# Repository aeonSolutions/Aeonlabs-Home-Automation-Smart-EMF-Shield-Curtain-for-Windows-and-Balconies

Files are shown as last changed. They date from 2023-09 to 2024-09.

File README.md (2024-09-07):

<p align="center">
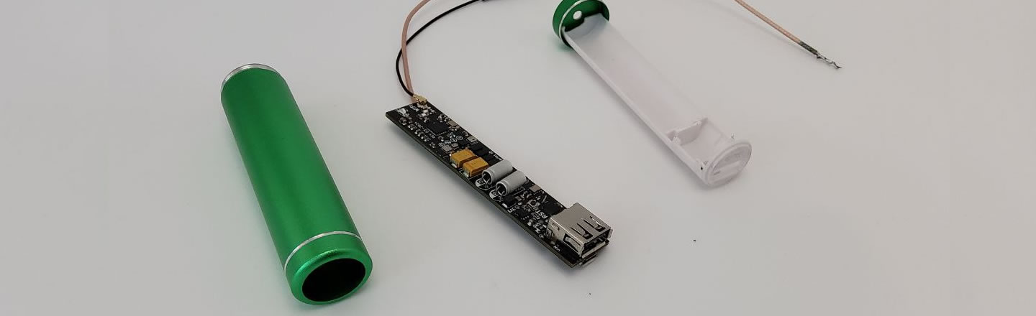
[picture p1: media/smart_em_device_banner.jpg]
   
</p>


 
 

<a href="https://trackgit.com">
trackgit-views
</a>




[](https://www.buymeacoffee.com/migueltomas)

**Navigation** | [AeonLabs Main Index](https://github.com/aeonSolutions/aeonSolutions/blob/main/aeonSolutions-Main-Index.md)  >>  [Open Hardware Electronics](https://github.com/aeonSolutions/PCB-Prototyping-Catalogue)   >>   [Home-Automation](https://github.com/aeonSolutions/PCB-Prototyping-Catalogue/tree/main/Home-Automation)  >>  [Safety & Health](https://github.com/aeonSolutions/AeonLabs-Safety-Health)     >>  Smart EMF Shield Curtain for Windows and Balconies

<p align="right">
 <a href="https://github-com.translate.goog/aeonSolutions/Aeonlabs-Home-Automation-Smart-EMF-Shield-Curtain-for-Windows-and-Balconies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">Change language</a> <br>
Last update 07-09-2024 <br> <br>
partially sponsored by <br> 
    <a href="https://www.seeedstudio.com/fusion.html">
       
    </a>
</p>

⚠️ **Start by reading the documentation first**. [Click here to open it](https://github.com/aeonSolutions/AeonLabs-Safety-Health/wiki) 

# Smart EMF Shield Curtain for Windows and Balconies

<p align="left"> 
  
<b>Status:</b>
 Hardware electronics are Fully tested and working. The first 🥇 release of the firmware code is now available. <br>
&nbsp; Looking for someone available to collaborate on the firmware coding. If you like this project and want faster development, prototyping, and testing consider a donation or sponsoring. thank you 🙏.
 </p>

<p align="center">  
   <a href="https://www.hackster.io/mtpsilva/an-open-smart-device-for-emf-emp-monitoring-in-a-window-5b020f">
      
   </a>
</p>

## The problem
nowadays many are sensitive to electromagnetic frequency radiation mainly due to excessive exposure above natural and healthy limits. There are many solutions to mitigate exposure to this kind of radiation however none have the ability to collect EMF energy values directly from a window or access door to a balcony.

## The idea
This smart device is intended to be installed and fixed into a copper electromagnetic (EM) shield on any EM indoor window or balcony door. It has the main ability to collect EM sensor data from the curtain itself and send it to a public data repository, for instance, a #dataverse (see www.dataverse.org)

<p align="center">
  <a href="https://www.customtintsolutions.com/window-film-benefits/rf-blocking/" target="_blank">
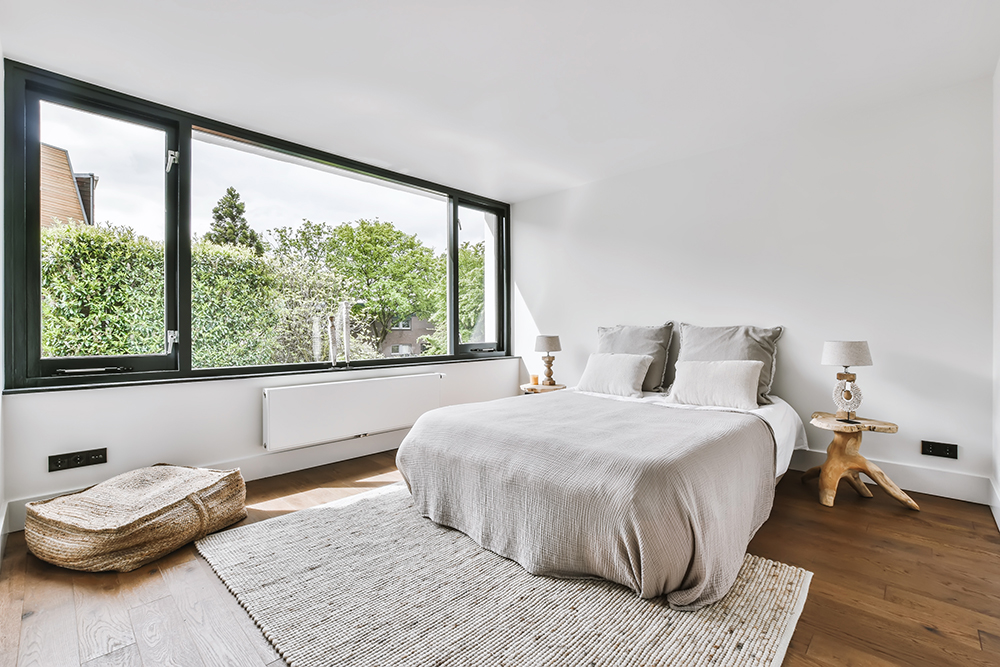
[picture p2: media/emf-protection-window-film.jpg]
      </a> <br>
   <sup> Figure 1- Example of a window in a room where this Smart Device can be installed</sup>
</p>

## Total Cost of this Project
The total cost of this project to date is listed below:
- Work hours dedicated to this project: >300 w.h <br>
  This includes research and study about Bio EM RF, building this repository, and other useless miscellaneous online tasks. <br>
  hardware electronics assembly and testing, several times.
- Electronic components  >200 eur
- Aluminium Enclosure Case and other materials ~20 eur ( [buy one on AliExpress ](https://s.click.aliexpress.com/e/_DkqC3wL) )

<p align="center">
    <a href="https://github.com/aeonSolutions/PCB-Prototyping-Catalogue/blob/main/become_a_sponsor/aeonlabs-github-sponsorship-agreement.docx">
        
    </a>
    <a href="https://github.com/sponsors/aeonSolutions">
        
    </a>
</p>

See [here](https://github.com/aeonSolutions/AeonLabs-Safety-Health) who sponsored, to this date, the Safety & Health project. 

<br>

## Important Information
The smart safety & health solution is for the kind of wireless aggression that behaves like ripples in a pond. For instance Wireless electromagnetic radios, including those found on smartphones, tablets, wifi routers at home, and many more.

**This smart device is not able to detect wireless aggressions targeted to a person's body and individual. For instance, using some kind of beam-forming device or technologies**. For example, Laser and laser-like kind of devices and kind of technologies. 

**When installing this smart solution, take action and be conscious that the aggression/aggressor may change to other types and kinds of "wireless devices" this smart device is unable to detect**.  

**Always use this smart device connected to a public data repository with LIVE data streams. At the same time, notify the authorities immediately and provide the web address link where the public data repository can be found**. Data repositories based on Harvard's www.dataverse.org are currently the most suited (not ideal) for the smart solution provided. 

**Be advised**

Known open data repositories partially compatible with these smart devices:
- www.dataverse.org [partial compatible] (open firmware provided here uses a dataverse repository API)
- www.figshare.com [partial compatible]
- www.datadryad.org [not compatible; no API]

<br>

<p align="center">
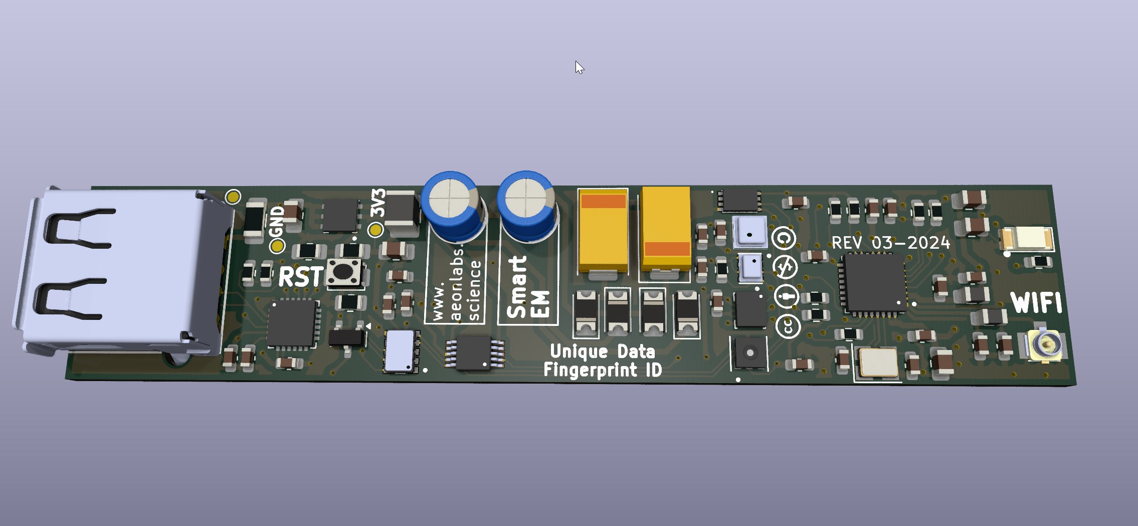
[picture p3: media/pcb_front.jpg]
     <br>
 <sup> Figure 2 - 3D rendering in KiCad of the hardware electronics </sup>
</p>

<p align="center">
<strong> <a href="https://aeonsolutions.github.io/sponsor/em_radiation/">Interactive view of the PCB Layout</a> </strong> &nbsp;
  <strong> <a href="https://aeonsolutions.github.io/sponsor/em_radiation//circuit_schematic.html">Interactive view of the circuit schematic</a> </strong> <br>
 <sup>Click to view the latest revision</sup>
</p>

This device is designed to burn out every time an electromagnetic pulse, spark, or other EMF has a too-high energy. This way the victim can use the burnt device as evidence when presenting a complaint to the authorities.

stay safe.

<p align="center">
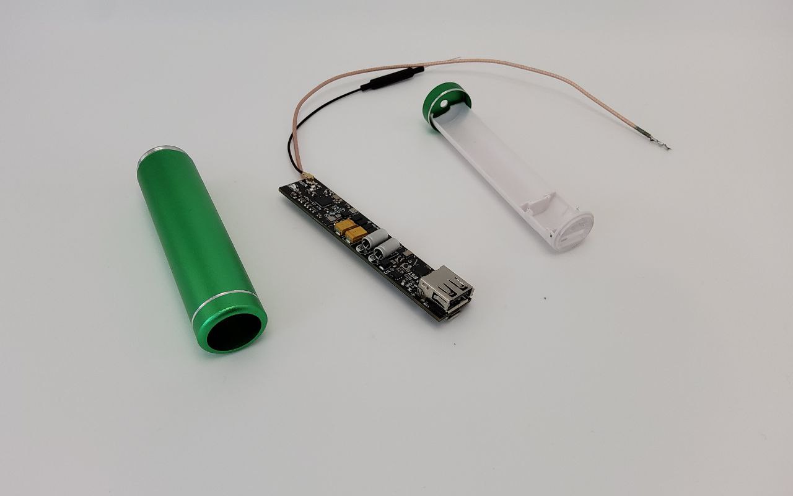
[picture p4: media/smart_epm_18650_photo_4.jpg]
    <br>
 <sup> Figure 3 - Smart EM Device Already Assemble and ready to be installed on the Aluminium Enclosure</sup>
</p>

## Compatibility

<p align="center">
 <a href"https://www.apple.com/shop/accessories/all/homekit">

 </a>
<a href="https://home.google.com"> 
 
 </a>
<a href="https://www.home-assistant.io">  
 
 </a>
<a href="https://csa-iot.org/all-solutions/matter/">  
 
 </a>
<a href="https://csa-iot.org/all-solutions/matter/">  
 
 </a>
</p>

###  Status
  Hardware electronics are Fully tested and working. The first 🥇 release of the firmware code is now available.
  
  <p align="center">


</p>

[January 1, 2024] - The firmware 1.0.0 for Over the Air Updates is now released to the public. Goto the [releases section](https://github.com/aeonSolutions/Aeonlabs-Home-Automation-Smart-EMF-Shield-Curtain-for-Windows-and-Balconies/releases/tag/openFirmware) to learn more.  

<br>

## OEM Firmware code
The OEM version of the firmware code can be found in the folder **OEM firmware code**.  It has by default OTA updates, meaning the smart concrete curing device automatically updates it self when newer updated versions are made available here.  

This code uses my own ESP32 C++ class libraries to expedite the development of the code of ESP32 microcontrollers. The repository is located in the [open source software section](https://github.com/aeonSolutions/aeonlabs-ESP32-C-Base-Firmware-Libraries#readme).

#### Send the collected sensor data to this repository
On this repository, there's a special folder, named [datasets](https://github.com/aeonSolutions/AeonLabs-Safety-Health/tree/main/Measurements/datasets), where anyone is able to upload dataset files directly from their open smart devices. This folder is intended to facilitate sharing of "electromagnetic" measurements among anyone with interest and capable of studying and analyzing it in search of EM anomalies to improve detection of the open hardware electronics made available here. **Anyone is invited to participate, cost-free**. 

&nbsp;&nbsp; To assist you with the firmware programming, there's a C++ test code compatible with all Arduino devices that anyone can use to speed up the programming of the open smart device. Here's the link: <br>
https://github.com/aeonSolutions/Aeonlabs-Arduino_Hardware_Test_Code/tree/main/github_api_test_upload <br>
Any questions on how to do it, send me a message on the Discord Server:

<div align="center">



</div>

<br>

## What one additionally needs
- [USB to UART/USB TTL firmware burner for 5V and 3.3V MCUs ](https://github.com/aeonSolutions/PCB-Prototyping-Catalogue/blob/main/DIY-Maker/README.md)
- [Radiation Shield Curtain](https://s.click.aliexpress.com/e/_DC76f4j) or any other conducting material or conductive glass window
  <p align="center"> 
 <a href="https://s.click.aliexpress.com/e/_DC76f4j" target="_blank">
     
  </a>
</p>

- [4.2V Lipo Battery](https://s.click.aliexpress.com/e/_Dl3iRpl)
  
<br />
<br />

**Get a Notification on every PCB update**

| [](https://www.tindie.com/stores/aeonlabs/) | You can fill in your [email here (Google form)](https://docs.google.com/forms/d/e/1FAIpQLScErMgQYRdA-umvCjvTPPrCO7Lg1QYowTxb7vfa8cTfrcPEAA/viewform?usp=pp_url) and I'll send a reminder when a new PCB prototype is made available here or a new revision for an existing PCB. Stay tuned! |
|---|---|

<br>

<br />
<br />

## Author

You can get in touch with me on my LinkedIn Profile:

#### Miguel Tomas



<a href="https://stackexchange.com/users/18907312/miguel-silva">profile for Miguel Silva on Stack Exchange, a network of free, community-driven Q&A sites</a>



You can also follow my GitHub Profile to stay updated about my latest projects: 

<br>

**Hire me** <br>
See [here](https://github.com/aeonSolutions/PCB-Prototyping-Catalogue/wiki/How-to-Hire-AeonLabs) how to hire AeonLabs.

<br>

### Be supportive of my dedication and work towards technology education and buy me a cup of coffee
The PCB design Files I provide here for anyone to use are free. If you like this Smart Device or use it, please consider buying me a cup of coffee, a slice of pizza, or a book to help me study, eat, and think new PCB design files.

<p align="center">
    <a href="https://www.buymeacoffee.com/migueltomas">
        
    </a>
</p>

### Make a donation on PayPal
Make a donation on PayPal and get a TAX refund*.

<p align="center">
    <a href="http://paypal.me/mtpsilva">
        
    </a>
</p>

### Support all these open hardware projects and become a GitHub sponsor  
Did you like any of my PCB KiCad Designs? Help and Support my open work to all by becoming a GitHub sponsor.

<p align="center">
    <a href="https://github.com/aeonSolutions/PCB-Prototyping-Catalogue/blob/main/become_a_sponsor/aeonlabs-github-sponsorship-agreement.docx">
        
    </a>
    <a href="https://github.com/sponsors/aeonSolutions">
        
    </a>
</p>

### License

Before proceeding to download any of AeonLabs open source code for software solutions and/or open hardware electronics for smart devices and data acquisition make sure you are choosing the right license for your project. See [AeonLabs Solutions for Open Hardware & Open Source Code](https://github.com/aeonSolutions/PCB-Prototyping-Catalogue/wiki/AeonLabs-Solutions-for-Open-Hardware-&-Source-Development) for more information. For commercial business solutions contact AeonLabs for more information ℹ️ using the contacts above. Thank you 🙏.

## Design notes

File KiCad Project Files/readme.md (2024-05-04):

[PCB-Prototyping-Catalogue](https://github.com/aeonSolutions/PCB-Prototyping-Catalogue)  >>   [Home-Automation](https://github.com/aeonSolutions/PCB-Prototyping-Catalogue/tree/main/Home-Automation)  >>  [Home Automation Safety & Health](https://github.com/aeonSolutions/PCB-Prototyping-Catalogue/blob/main/Home%20Automation%20Safety%20%26%20Health/readme.md)   >>  Smart EMF Shield Curtain for Windows and Balconies

<p align="right">
 <a href="https://github-com.translate.goog/aeonSolutions/Aeonlabs-Home-Automation-Smart-EMF-Shield-Curtain-for-Windows-and-Balconies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">Change language</a> <br>
Last update 04-05-2024 <br> <br>
partially sponsored by <br> 
    <a href="https://www.seeedstudio.com/fusion.html">
       
    </a>
</p>

<br>

This folder contains the KiCad Project files, for the hardware electronics of the Smart EMF Shield Curtain for Windows and Balconies.  Each KiCad project is available with a [creative commons share alike non-commercial license](https://creativecommons.org/licenses/by-nc-sa/4.0/deed.en). 

<p align="center">
<strong> <a href="https://aeonsolutions.github.io/sponsor/em_radiation/">Interactive view of the PCB Layout</a> </strong> &nbsp;
  <strong> <a href="https://aeonsolutions.github.io/sponsor/em_radiation//circuit_schematic.html">Interactive view of the circuit schematic</a> </strong> <br>
 <sup>Click to view the latest revision</sup>
</p>

However, they're not fully complete. If you like it and are looking to use it on your projects, you can download the complete Kicad project files with a one-time donation, [click here](https://github.com/sponsors/aeonSolutions) to learn how,  and don't forget to include it in a message the name of the module/hardware electronics you need. <br> Thank you 🙏.

### Support all these open hardware projects and become a GitHub sponsor  
Did you like any of my PCB KiCad Designs? Help and Support my open work to all by becoming a GitHub sponsor.

<p align="center">
    <a href="https://github.com/aeonSolutions/PCB-Prototyping-Catalogue/blob/main/become_a_sponsor/aeonlabs-github-sponsorship-agreement.docx">
        
    </a>
    <a href="https://github.com/sponsors/aeonSolutions">
        
    </a>
</p>

#

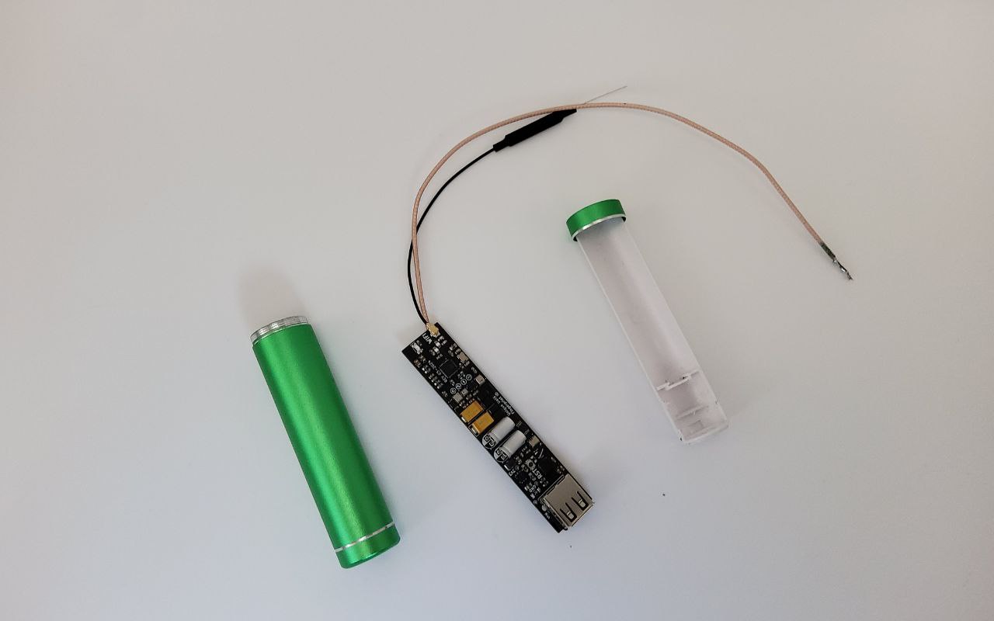
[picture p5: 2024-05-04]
media/smart_epm_18650_photo_3.jpg

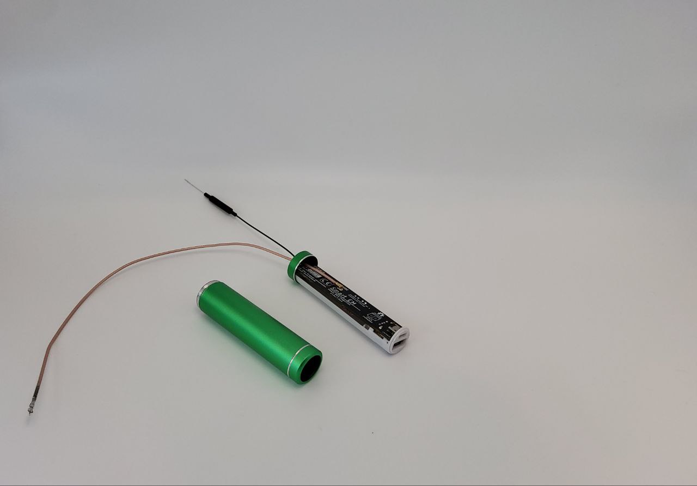
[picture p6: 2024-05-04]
media/smart_epm_18650_photo_2.jpg

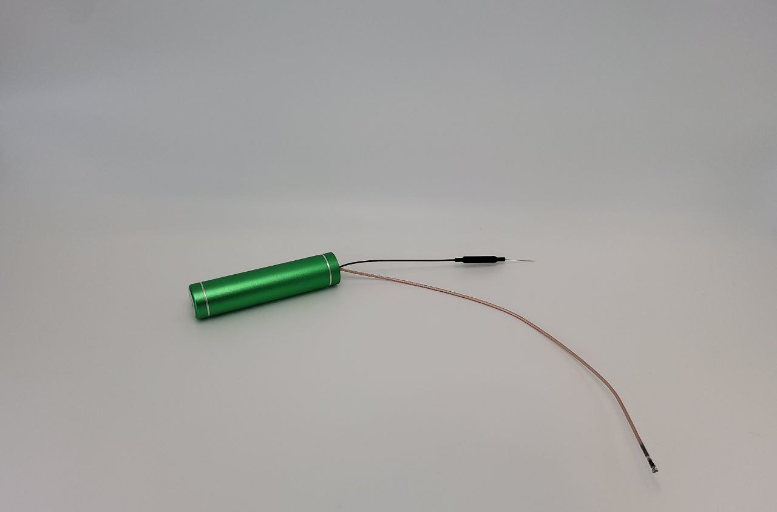
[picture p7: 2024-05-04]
media/smart_epm_18650_photo_1.jpg

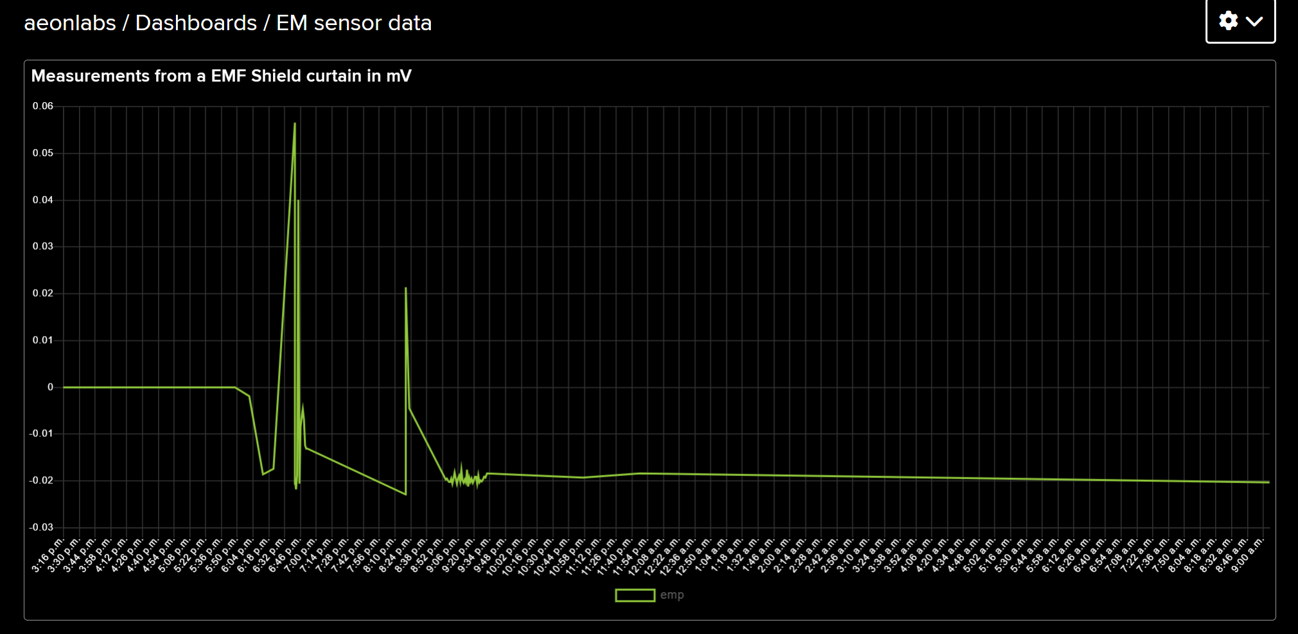
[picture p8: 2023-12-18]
media/emf_data_plot.png

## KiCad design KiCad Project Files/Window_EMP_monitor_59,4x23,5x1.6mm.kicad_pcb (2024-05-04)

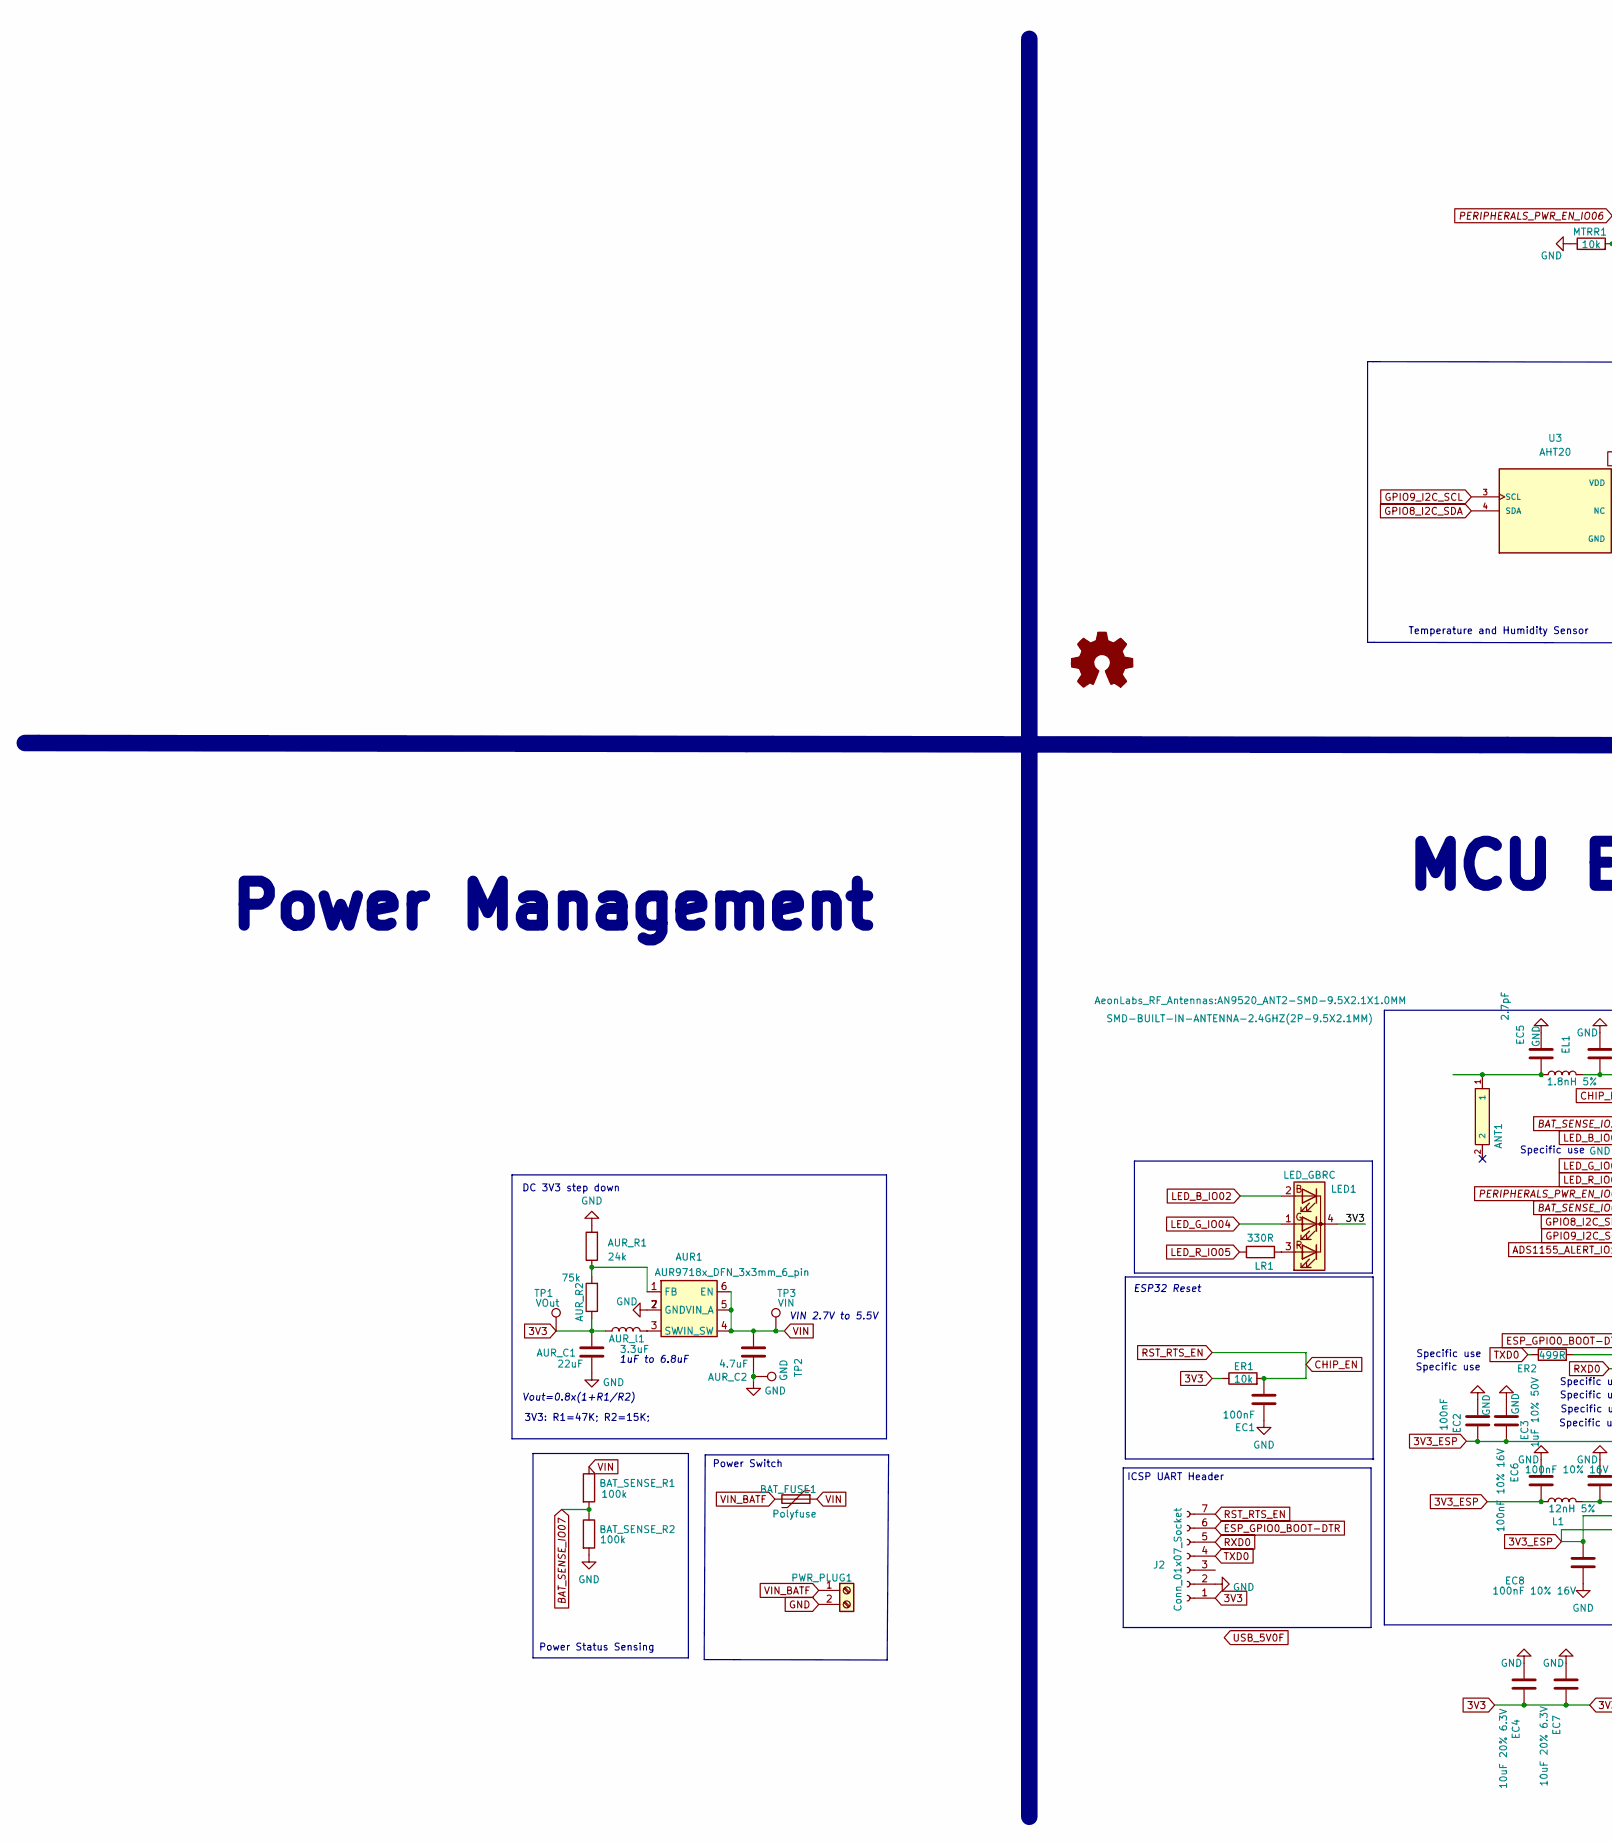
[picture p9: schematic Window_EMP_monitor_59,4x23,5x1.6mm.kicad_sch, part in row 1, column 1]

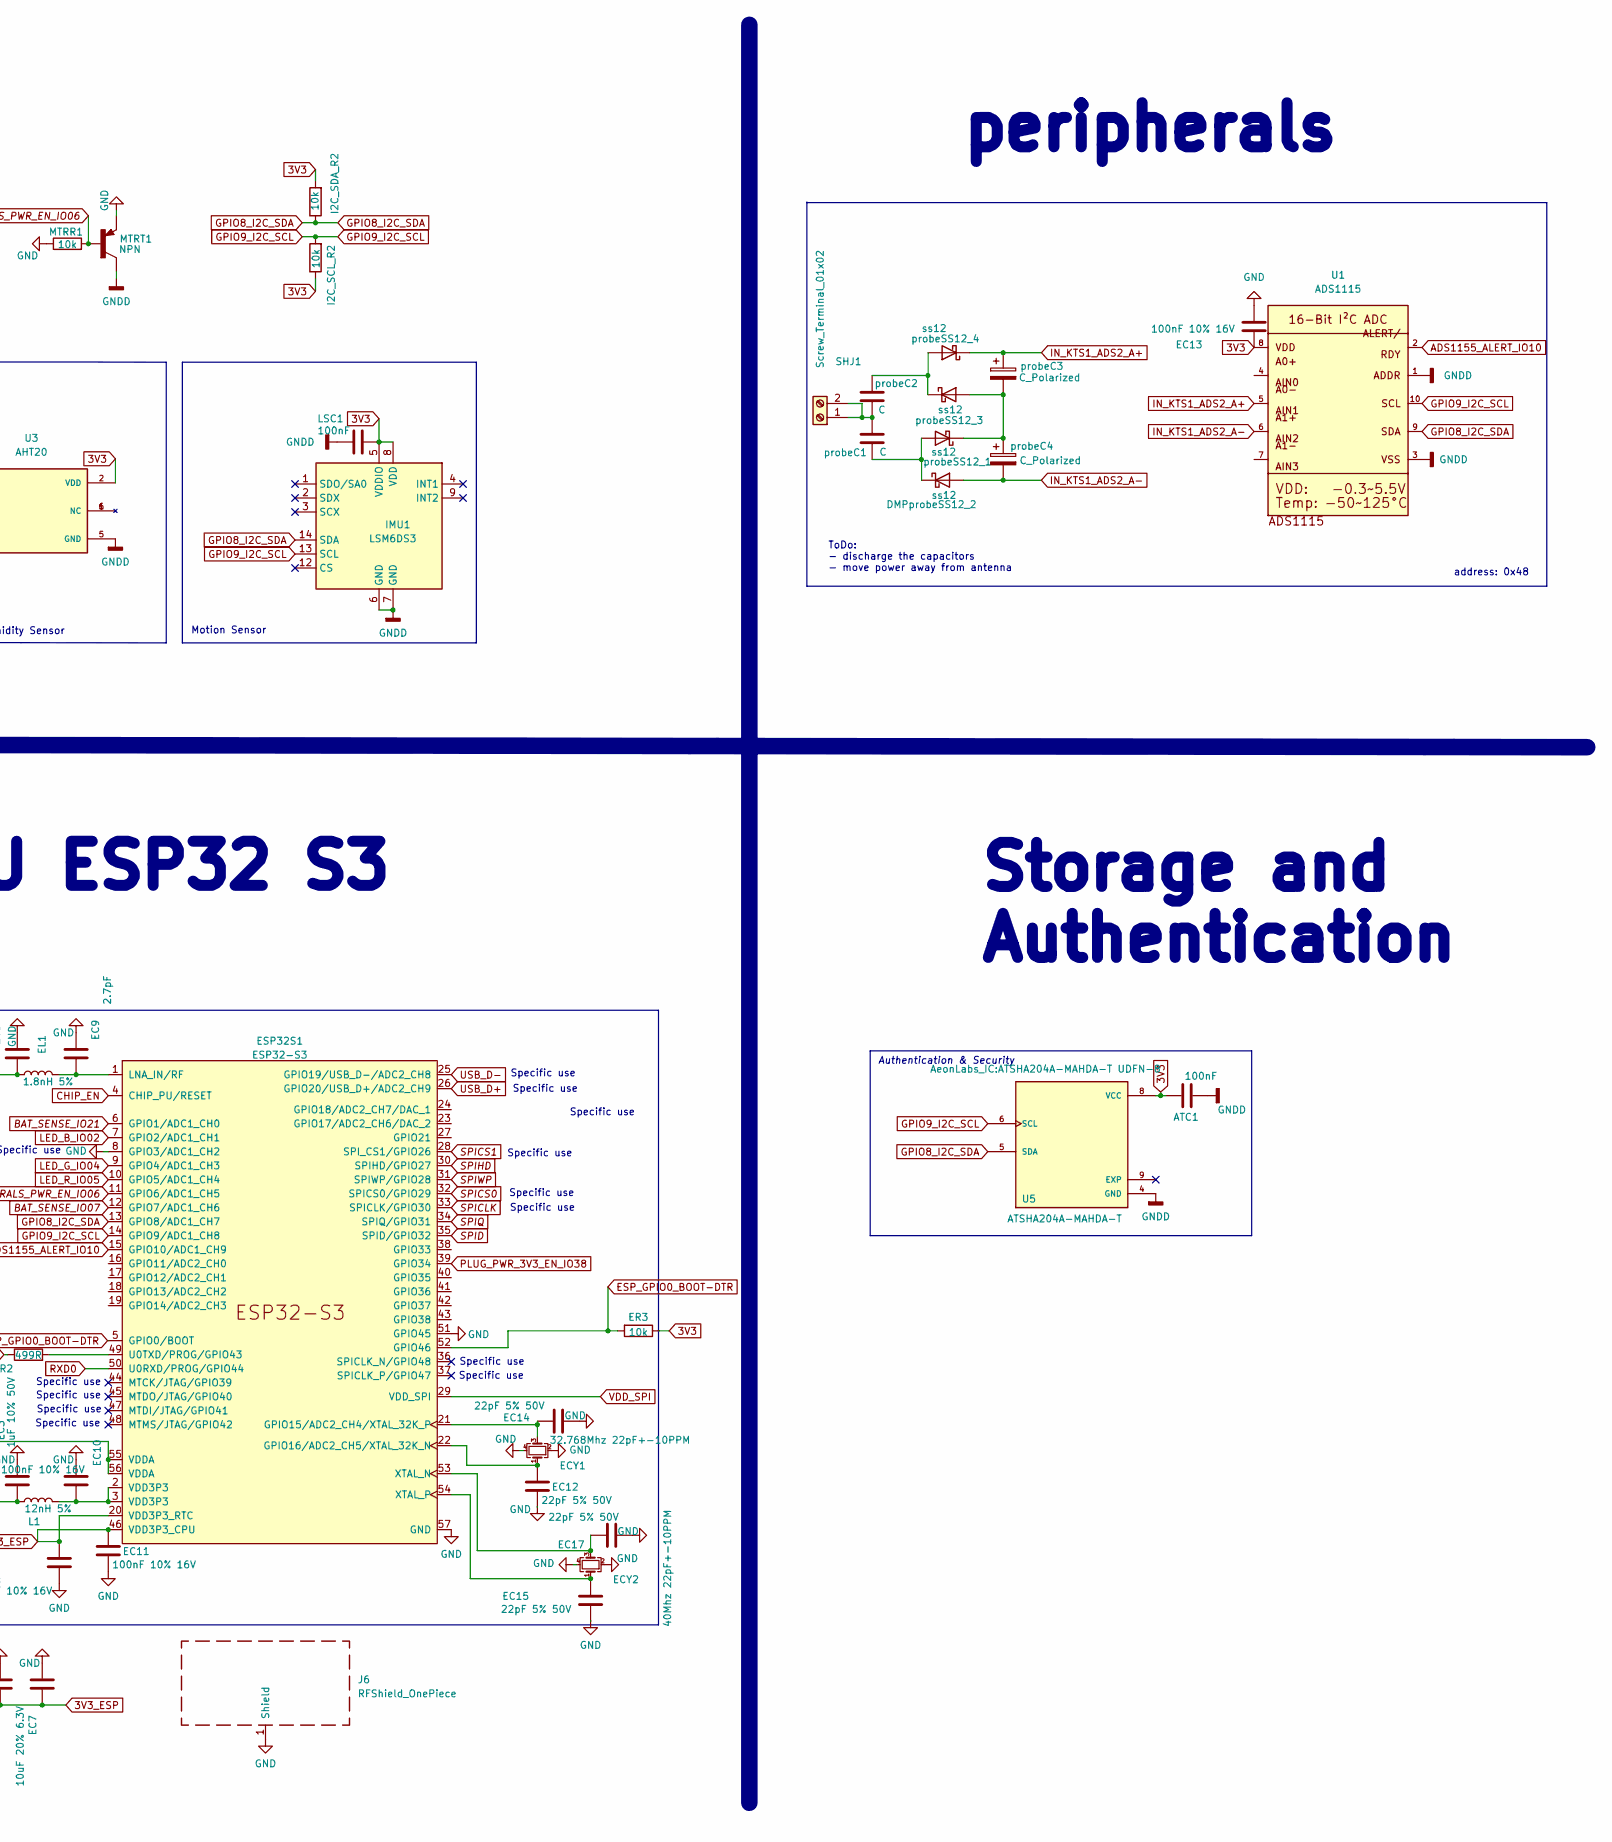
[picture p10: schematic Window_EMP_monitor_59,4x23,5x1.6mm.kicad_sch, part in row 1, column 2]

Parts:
ANT1: SMD-BUILT-IN-ANTENNA-2.4GHZ(2P-9.5X2.1MM); AN9520_ANT2-SMD-9.5X2.1X1.0MM
ATC1: 100nF; C_0603_1608Metric
AUR1: AUR9718x_DFN_3x3mm_6_pin; AUR9718 ST1S09 SON95P300X300X100-7N
AUR_C1: 22uF; C_0805_2012Metric_Pad1.18x1.45mm_HandSolder
AUR_C2: 4.7uF; C_0805_2012Metric_Pad1.18x1.45mm_HandSolder
AUR_R1: 24k; R_0805_2012Metric_Pad1.20x1.40mm_HandSolder
AUR_R2: 75k; R_0805_2012Metric_Pad1.20x1.40mm_HandSolder
AUR_l1: 3.3uF; L_1210_3225Metric
BAT_FUSE1: Polyfuse; Fuse_1206_3216Metric_Pad1.42x1.75mm_HandSolder
BAT_SENSE_R1, BAT_SENSE_R2: 100k; R_0603_1608Metric
DMPprobeSS12_2: ss12; D_1206_3216Metric
EC1, EC2: 100nF; C_0603_1608Metric
EC3: 1uF 10% 50V; C_0805_2012Metric
EC4, EC7: 10uF 20% 6.3V; C_0805_2012Metric
EC5, EC9: 2.7pF; C_0603_1608Metric
EC6, EC8, EC10, EC11, EC13: 100nF 10% 16V; C_0603_1608Metric
EC12, EC14, EC15, EC17: 22pF 5% 50V; C_0603_1608Metric
ECY1: 32.768Mhz 22pF+-10PPM; Crystal_SMD_3225-4Pin_3.2x2.5mm
ECY2: 40Mhz 22pF+-10PPM; Crystal_SMD_3225-4Pin_3.2x2.5mm
EL1: 1.8nH 5%; L_0805_2012Metric
ER1, ER3: 10k; R_0603_1608Metric
ER2: 499R; R_0603_1608Metric
ESP32S1: ESP32-S3; QFN-56-1EP_7x7mm_P0.4mm_EP5.6x5.6mm
I2C_SCL_R2, I2C_SDA_R2: 10k; R_0603_1608Metric
IMU1: LSM6DS3; LSM6DS3 PQFN50P300X250X86-14N
J2: Conn_01x07_Socket; SOIC_clipProgSmall
J6: RFShield_OnePiece; ESP32-S3 GND Shield
L1: 12nH 5%; L_0805_2012Metric
LED1: LED_GBRC; LED_1206_3210_RGB_Metric
LR1: 330R; R_0603_1608Metric
LSC1: 100nF; C_0603_1608Metric
MTRR1: 10k; R_0805_2012Metric
MTRT1: NPN; SOT-23; PARTREV C2001
PWR_PLUG1: Screw_Terminal_01x02; JST_EH_S2B-EH_1x02_P2.50mm_Horizontal
SHJ1: Screw_Terminal_01x02; JST_SH_SM02B-SRSS-TB_1x02-1MP_P1.00mm_Horizontal
TP1: VOut; TestPoint_Pad_D1.0mm
TP2: GND; TestPoint_Pad_D1.0mm
TP3: VIN; TestPoint_Pad_D1.0mm
U1: ADS1115; ASD1155
U3: AHT20; AHT20 PSON100P300X300X110-6N; PARTREV V1.0
U5: ATSHA204A-MAHDA-T; ATSHA204A-MAHDA-T UDFN-8; PART_REV A
probeC1, probeC2: C; CP_EIA-7343-31_Kemet-D
probeC3, probeC4: C_Polarized; CP_Radial_D5.0mm_P2.50mm
probeSS12_1, probeSS12_3, probeSS12_4: ss12; D_1206_3216Metric

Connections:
3V3: ATC1.2, AUR_C1.1, AUR_R2.1, AUR_l1.1, EC2.2, EC3.2, EC4.1, EC6.1, EC7.1, EC8.1, EC11.1, EC13.2, ER1.1, ER3.1, ESP32S1.20 (VDD3P3_RTC), ESP32S1.46 (VDD3P3_CPU), ESP32S1.55 (VDDA), ESP32S1.56 (VDDA), I2C_SCL_R2.1, I2C_SDA_R2.2, IMU1.5 (VDDIO), IMU1.8 (VDD), J2.1, L1.1, LED1.4 (K), LSC1.1, TP1.1, U1.8, U3.2 (VDD), U5.8 (VCC)
ADS1155_ALERT_IO10: ESP32S1.15 (GPIO10/ADC1_CH9), U1.2
BAT_SENSE_IO07: BAT_SENSE_R1.2, BAT_SENSE_R2.1, ESP32S1.12 (GPIO7/ADC1_CH6)
BAT_SENSE_IO21: ESP32S1.6 (GPIO1/ADC1_CH0)
CHIP_EN: EC1.2, ER1.2, ESP32S1.4 (CHIP_PU/RESET), J2.7
ESP_GPIO0_BOOT-DTR: ER3.2, ESP32S1.5 (GPIO0/BOOT), ESP32S1.52 (GPIO46), J2.6
GND: AUR1.2 (GND), AUR1.7 (GND), AUR_C1.2, AUR_C2.2, AUR_R1.2, BAT_SENSE_R2.2, EC1.1, EC2.1, EC3.1, EC4.2, EC5.2, EC6.2, EC7.2, EC8.2, EC9.2, EC10.2, EC11.2, EC12.2, EC13.1, EC14.2, EC15.2, EC17.2, ECY1.2, ECY1.4, ECY2.2, ECY2.4, ESP32S1.8 (GPIO3/ADC1_CH2), ESP32S1.51 (GPIO45), ESP32S1.57 (GND), J2.2, MTRR1.1, MTRT1.2, PWR_PLUG1.2, TP2.1
GNDD: ATC1.1, IMU1.6 (GND), IMU1.7 (GND), LSC1.2, MTRT1.3, U1.1, U1.3, U3.5 (GND), U5.4 (GND)
GPIO8_I2C_SDA: ESP32S1.13 (GPIO8/ADC1_CH7), I2C_SDA_R2.1, IMU1.14 (SDA), U1.9, U3.4 (SDA), U5.5 (SDA)
GPIO9_I2C_SCL: ESP32S1.14 (GPIO9/ADC1_CH8), I2C_SCL_R2.2, IMU1.13 (SCL), U1.10, U3.3 (SCL), U5.6 (SCL)
IN_KTS1_ADS2_A+: U1.5, probeC3.1, probeSS12_4.1 (K)
IN_KTS1_ADS2_A-: DMPprobeSS12_2.2 (A), U1.6, probeC4.2
LED_B_IO02: ESP32S1.7 (GPIO2/ADC1_CH1), LED1.2 (BA)
LED_G_IO04: ESP32S1.9 (GPIO4/ADC1_CH3), LED1.1 (GA)
LED_R_IO05: ESP32S1.10 (GPIO5/ADC1_CH4), LR1.1
unnamed: ANT1.1, EC5.1, EL1.1
unnamed: AUR1.1 (FB), AUR_R1.1, AUR_R2.2
unnamed: AUR1.3 (SW), AUR_l1.2
unnamed: DMPprobeSS12_2.1 (K), probeC1.2, probeSS12_1.2 (A)
unnamed: EC10.1, ESP32S1.2 (VDD3P3), ESP32S1.3 (VDD3P3), L1.2
unnamed: EC14.1, ECY1.3, ESP32S1.21 (GPIO15/ADC2_CH4/XTAL_32K_P)
unnamed: EC12.1, ECY1.1, ESP32S1.22 (GPIO16/ADC2_CH5/XTAL_32K_N)
unnamed: EC9.1, EL1.2, ESP32S1.1 (LNA_IN/RF)
unnamed: ER2.2, ESP32S1.49 (U0TXD/PROG/GPIO43)
unnamed: EC17.1, ECY2.3, ESP32S1.53 (XTAL_N)
unnamed: EC15.1, ECY2.1, ESP32S1.54 (XTAL_P)
unnamed: LED1.3 (RA), LR1.2
unnamed: SHJ1.1, SHJ1.2, probeC1.1, probeC2.2
unnamed: probeC3.2, probeC4.1, probeSS12_1.1 (K), probeSS12_3.2 (A)
unnamed: probeC2.1, probeSS12_3.1 (K), probeSS12_4.2 (A)
PERIPHERALS_PWR_EN_IO06: ESP32S1.11 (GPIO6/ADC1_CH5), MTRR1.2, MTRT1.1
PLUG_PWR_3V3_EN_IO38: ESP32S1.39 (GPIO34)
RXD0: ESP32S1.50 (U0RXD/PROG/GPIO44), J2.5
SPICLK: ESP32S1.33 (SPICLK/GPIO30)
SPICS0: ESP32S1.32 (SPICS0/GPIO29)
SPICS1: ESP32S1.28 (SPI_CS1/GPIO26)
SPID: ESP32S1.35 (SPID/GPIO32)
SPIHD: ESP32S1.30 (SPIHD/GPIO27)
SPIQ: ESP32S1.34 (SPIQ/GPIO31)
SPIWP: ESP32S1.31 (SPIWP/GPIO28)
TXD0: ER2.1, J2.4
USB_D+: ESP32S1.26 (GPIO20/USB_D+/ADC2_CH9)
USB_D-: ESP32S1.25 (GPIO19/USB_D-/ADC2_CH8)
VDD_SPI: ESP32S1.29 (VDD_SPI)
VIN: AUR1.4 (VIN_SW), AUR1.5 (VIN_A), AUR1.6 (EN), AUR_C2.1, BAT_FUSE1.1, BAT_SENSE_R1.1, TP3.1
VIN_BATF: BAT_FUSE1.2, PWR_PLUG1.1

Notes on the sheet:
Specific use
peripherals
DC 3V3 step down
Power Switch
address: 0x48
Temperature and Humidity Sensor
Power Status Sensing
ToDo: - discharge the capacitors - move power away from antenna
Vout=0.8x(1+R1/R2)
Motion Sensor
ESP32 Reset
1uF to 6.8uF
Storage and Authentication
Power Management
ICSP UART Header
MCU ESP32 S3
Authentication & Security
VIN 2.7V to 5.5V
3V3: R1=47K; R2=15K;

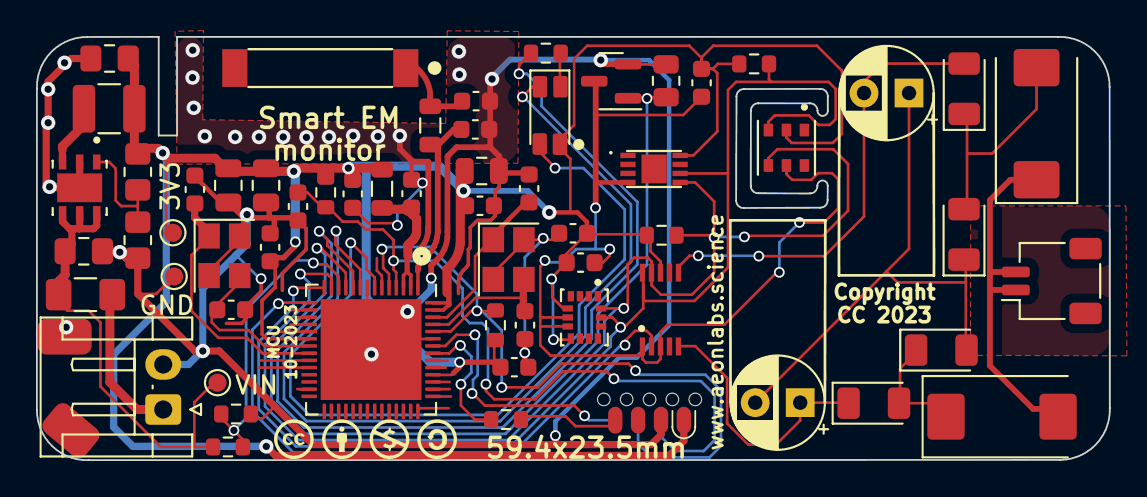
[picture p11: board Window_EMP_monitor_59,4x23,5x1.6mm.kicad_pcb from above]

Board: 2 copper layers, 59.6 x 23.5 mm, 60 parts (0 on the bottom side), 34 nets.

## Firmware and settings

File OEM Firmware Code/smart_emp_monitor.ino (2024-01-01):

/*
  Copyright (c) 2023 Miguel Tomas, http://www.aeonlabs.science

  License Attribution-NonCommercial-ShareAlike 4.0 International (CC BY-NC-SA 4.0)
  You are free to:
   Share — copy and redistribute the material in any medium or format
   Adapt — remix, transform, and build upon the material

  The licensor cannot revoke these freedoms as long as you follow the license terms. Under the following terms:
  Attribution — You must give appropriate credit, provide a link to the license, and indicate if changes were made.
  You may do so in any reasonable manner, but not in any way that suggests the licensor endorses you or your use.

  NonCommercial — You may not use the material for commercial purposes.

  ShareAlike — If you remix, transform, or build upon the material, you must distribute your contributions under
  the same license as the original.

  No additional restrictions — You may not apply legal terms or technological measures that legally restrict others
  from doing anything the license permits.

  Notices:
  You do not have to comply with the license for elements of the material in the public domain or where your use
  is permitted by an applicable exception or limitation.
  No warranties are given. The license may not give you all of the permissions necessary for your intended use.
  For example, other rights such as publicity, privacy, or moral rights may limit how you use the material.


  Before proceeding to download any of AeonLabs software solutions for open-source development
  and/or PCB hardware electronics development make sure you are choosing the right license for your project. See
  https://github.com/aeonSolutions/PCB-Prototyping-Catalogue/wiki/AeonLabs-Solutions-for-Open-Hardware-&-Source-Development
  for Open Hardware & Source Development for more information.

*/

#define uS_TO_S_FACTOR 1000000

/************************* Adafruit.io Setup *********************************/
//required message queue telemetry transport protocol to subscribe and publish feeds
#include "Adafruit_MQTT.h"
#include "Adafruit_MQTT_Client.h"

// the adafruit server to connect
#define AIO_SERVER    "io.adafruit.com"

// the port to connect
#define AIO_SERVERPORT 1883

// get this key from your own Adafruit Account
#define AIO_USERNAME "XXXXXXXX"
#define AIO_KEY "XXXXXXXXXXXXXXXXXXX"
#include <WiFi.h>
WiFiClient wclient;

Adafruit_MQTT_Client mqtt(&wclient, AIO_SERVER, AIO_SERVERPORT, AIO_USERNAME, AIO_KEY);

//Feeds Settings

//temperature value that will be read through BMP180 sensor
Adafruit_MQTT_Publish temp = Adafruit_MQTT_Publish(&mqtt, AIO_USERNAME "/feeds/temp");

//pressure value that will be read through BMP180 sensor
Adafruit_MQTT_Publish humidity = Adafruit_MQTT_Publish(&mqtt, AIO_USERNAME "/feeds/humidity");

//altitude value that will be read through BMP180 sensor
Adafruit_MQTT_Publish emp = Adafruit_MQTT_Publish(&mqtt, AIO_USERNAME "/feeds/emp");


//----------------------------------------------------------------------------------------
// Components Testing  **************************************
bool SCAN_I2C_BUS = false;
bool TEST_FINGERPRINT_ID_IC = false;

//----------------------------------------------------------------------------------
#include <math.h>
#include <cmath>
#include "SPI.h"
#include <semphr.h>

#include "esp32-hal-psram.h"
// #include "rom/cache.h"
extern "C"
{
#include <esp_himem.h>
#include <esp_spiram.h>
}

#include <Wire.h>
// custom includes **********************************
#include "nvs_flash.h"  //preferences lib

// External sensor moeasurements
#include "telegram_emp.h"
TELEGRAM_EMP_CLASS* telegram = new TELEGRAM_EMP_CLASS();

// custom functions
#include "m_file_functions.h"

// Interface class ******************************
#include "interface_class.h"
INTERFACE_CLASS* interface = new INTERFACE_CLASS();
#define DEVICE_NAME "EMP Monitor"

// GBRL commands  ***************************
#include "gbrl.h"
GBRL gbrl = GBRL();

// Onboard sensors  *******************************
#include "onboard_sensors.h"
ONBOARD_SENSORS* onBoardSensors = new ONBOARD_SENSORS();

//
#include <Adafruit_ADS1X15.h>
Adafruit_ADS1115 ads;  /* Use this for the 16-bit version */
// Pin connected to the ALERT/RDY signal for new sample notification.
constexpr int READY_PIN = 10;


// unique figerprint data ID
#include "m_atsha204.h"

// serial comm
#include <HardwareSerial.h>
HardwareSerial UARTserial(0);

#include "mserial.h"
mSerial* mserial = new mSerial(true, nullptr);

// File class
#include <esp_partition.h>
#include "FS.h"
#include <LittleFS.h>
#include "m_file_class.h"

FILE_CLASS* drive = new FILE_CLASS(mserial);

// WIFI Class
#include <ESP32Ping.h>
#include "m_wifi.h"
#include "esp_wifi.h"
M_WIFI_CLASS* mWifi = new M_WIFI_CLASS();

// Certificates
#include "cert/github_cert.h"

/********************************************************************/
#include <BLEDevice.h>
#include <BLEServer.h>
#include <BLEUtils.h>
#include <BLE2902.h>

// See the following for generating UUIDs:
// https://www.uuidgenerator.net/

#define SERVICE_UUID           "6E400001-B5A3-F393-E0A9-E50E24DCCA9E" // UART service UUID
#define CHARACTERISTIC_UUID_RX "6E400002-B5A3-F393-E0A9-E50E24DCCA9E"
#define CHARACTERISTIC_UUID_TX "6E400003-B5A3-F393-E0A9-E50E24DCCA9E"

BLECharacteristic *pCharacteristicTX, *pCharacteristicRX;
BLEServer *pServer;
BLEService *pService;


bool BLE_advertise_Started = false;

bool newValueToSend = false;
String $BLE_CMD = "";
bool newBLESerialCommandArrived = false;
SemaphoreHandle_t MemLockSemaphoreBLE_RX = xSemaphoreCreateMutex();

float txValue = 0;
String valueReceived = "";


class MyServerCallbacks: public BLEServerCallbacks {
    void onConnect(BLEServer* pServer) {
      mWifi->setBLEconnectivityStatus (true);
      mserial->printStr("BLE connection init ", mserial->DEBUG_BOTH_USB_UART);

      interface->onBoardLED->led[0] = interface->onBoardLED->LED_BLUE;
      interface->onBoardLED->statusLED(100, 1);

      String dataStr = "Connected to the Smart Concrete Maturity device (" + String(interface->firmware_version) + ")" + String(char(10)) + String(char(13)) + "Type $? or $help to see a list of available commands" + String(char(10));
      dataStr += String(interface->rtc.getDateTime(true)) + String(char(10)) + String(char(10));

      if (mWifi->getNumberWIFIconfigured() == 0 ) {
        dataStr += "no WiFi Networks Configured" + String(char(10)) + String(char(10));
      }
      //interface->sendBLEstring(dataStr, mserial->DEBUG_TO_BLE);
    }

    void onDisconnect(BLEServer* pServer) {
      mWifi->setBLEconnectivityStatus (false);

      interface->onBoardLED->led[0] = interface->onBoardLED->LED_BLUE;
      interface->onBoardLED->statusLED(100, 0.5);
      interface->onBoardLED->led[0] = interface->onBoardLED->LED_RED;
      interface->onBoardLED->statusLED(100, 0.5);
      interface->onBoardLED->led[0] = interface->onBoardLED->LED_BLUE;
      interface->onBoardLED->statusLED(100, 0.5);

      pServer->getAdvertising()->start();
    }
};

class pCharacteristicTX_Callbacks: public BLECharacteristicCallbacks {
    void onWrite(BLECharacteristic *pCharacteristic) {
      String txValue = String(pCharacteristic->getValue().c_str());
      txValue.trim();
      mserial->printStrln("Transmitted TX Value: " + String(txValue.c_str()) , mserial->DEBUG_BOTH_USB_UART);

      if (txValue.length() == 0) {
        mserial->printStr("Transmitted TX Value: empty ", mserial->DEBUG_BOTH_USB_UART);
      }
    }

    void onRead(BLECharacteristic *pCharacteristic) {
      mserial->printStr("TX onRead...", mserial->DEBUG_BOTH_USB_UART);
      //pCharacteristic->setValue("OK");
    }
};

class pCharacteristicRX_Callbacks: public BLECharacteristicCallbacks {
    void onWrite(BLECharacteristic *pCharacteristic) {
      delay(10);

      String rxValue = String(pCharacteristic->getValue().c_str());
      rxValue.trim();
      mserial->printStrln("Received RX Value: " + String(rxValue.c_str()), mserial->DEBUG_BOTH_USB_UART );

      if (rxValue.length() == 0) {
        mserial->printStr("Received RX Value: empty " , mserial->DEBUG_BOTH_USB_UART);
      }

      $BLE_CMD = rxValue;
      mWifi->setBLEconnectivityStatus(true);

      xSemaphoreTake(MemLockSemaphoreBLE_RX, portMAX_DELAY);
      newBLESerialCommandArrived = true; // this needs to be the last line
      xSemaphoreGive(MemLockSemaphoreBLE_RX);

      delay(50);
    }

    void onRead(BLECharacteristic *pCharacteristic) {
      mserial->printStr("RX onRead..." , mserial->DEBUG_BOTH_USB_UART);
      //pCharacteristic->setValue("OK");
    }

};

// ********************************************************
// *************************  == SETUP == *****************
// ********************************************************
//variaveis que indicam o núcleo
static uint8_t taskCoreZero = 0;
static uint8_t taskCoreOne  = 1;

long int prevMeasurementMillis;


void setup() {
  ESP_ERROR_CHECK(nvs_flash_erase());
  nvs_flash_init();

  interface->settings_defaults();
  // Firmware Build Version / revision ______________________________
  interface->firmware_version = "1.0.0";

  // Serial Communication Init ______________________________
  interface->UARTserial = nullptr; // &UARTserial;
  mserial->DEBUG_TO = mserial->DEBUG_TO_UART;
  mserial->DEBUG_EN = true;
  mserial->DEBUG_TYPE = mserial->DEBUG_TYPE_VERBOSE; // DEBUG_TYPE_INFO;

  mserial->start(115200);

  // ......................................................................................................
  // .......................... START OF IO & PIN CONFIGURATION..............................................
  // ......................................................................................................

  // I2C IOs  __________________________
  interface->I2C_SDA_IO_PIN = 8;
  interface->I2C_SCL_IO_PIN = 9;
  int I2C_PWR_PIN=6;
  
  pinMode(I2C_PWR_PIN, OUTPUT);
  digitalWrite(I2C_PWR_PIN, HIGH);
  
  // WIRE.begin: SDA, SCL, FREQ
  bool result = Wire.begin( interface->I2C_SDA_IO_PIN , interface->I2C_SCL_IO_PIN ); //, 100000 );
  
  // Power Saving ____________________________________
  interface->LIGHT_SLEEP_EN = true;


  // ________________ Onboard LED  _____________
  interface->onBoardLED = new ONBOARD_LED_CLASS();
  interface->onBoardLED->LED_RED = 5;
  interface->onBoardLED->LED_BLUE = 2;
  interface->onBoardLED->LED_GREEN = 4;

  interface->onBoardLED->LED_RED_CH = 4;
  interface->onBoardLED->LED_BLUE_CH = 1;
  interface->onBoardLED->LED_GREEN_CH = 3;

  // ___________ MCU freq ____________________
  interface-> SAMPLING_FREQUENCY = 80;
  interface-> WIFI_FREQUENCY = 80; // min WIFI MCU Freq is 80-240
  interface->MIN_MCU_FREQUENCY = 80;
  interface-> SERIAL_DEFAULT_SPEED = 115200;

// _____________________ TELEGRAM _____________________________
  telegram->OWNER_CHAT_ID = "xxxxxxxxxxxx";
  // Initialize Telegram BOT
  telegram->BOTtoken = "xxxxxxxxxxxxxxxxxxxxxxxxxxxxxxxxxxx";  // your Bot Token (Get from Botfather)

  // ......................................................................................................
  // .......................... END OF IO & PIN CONFIGURATION..............................................
  // ......................................................................................................

  interface->onBoardLED->init();

  interface->onBoardLED->led[0] = interface->onBoardLED->LED_RED;
  interface->onBoardLED->statusLED(100, 0);

  //init storage drive ___________________________
  drive->partition_info();
  if (drive->init(LittleFS, "storage", 2, mserial,   interface->onBoardLED ) == false)
    while (1);

  //init interface ___________________________
  interface->init(mserial, true); // debug EN ON

  if ( !interface->loadSettings() ) {
    interface->onBoardLED->led[0] = interface->onBoardLED->LED_RED;
    interface->onBoardLED->led[0] = interface->onBoardLED->LED_GREEN;
    interface->onBoardLED->statusLED(100, 2);
  }

  // init onboard sensors ___________________________
  onBoardSensors->init(interface, mserial);

  if (SCAN_I2C_BUS) {
    onBoardSensors->I2Cscanner();
  }
  onBoardSensors->initOnboardSensors();

  mserial->printStrln("Getting differential reading from AIN0 (P) and AIN1 (N)");
  mserial->printStrln("ADC Range: +/- 6.144V (1 bit = 3mV/ADS1015, 0.1875mV/ADS1115)");

  // The ADC input range (or gain) can be changed via the following
  // functions, but be careful never to exceed VDD +0.3V max, or to
  // exceed the upper and lower limits if you adjust the input range!
  // Setting these values incorrectly may destroy your ADC!
  //                                                                ADS1015  ADS1115
  //                                                                -------  -------
  ads.setGain(GAIN_TWOTHIRDS);  // 2/3x gain +/- 6.144V  1 bit = 3mV      0.1875mV (default)
  // ads.setGain(GAIN_ONE);        // 1x gain   +/- 4.096V  1 bit = 2mV      0.125mV
  // ads.setGain(GAIN_TWO);        // 2x gain   +/- 2.048V  1 bit = 1mV      0.0625mV
  // ads.setGain(GAIN_FOUR);       // 4x gain   +/- 1.024V  1 bit = 0.5mV    0.03125mV
  // ads.setGain(GAIN_EIGHT);      // 8x gain   +/- 0.512V  1 bit = 0.25mV   0.015625mV
  // ads.setGain(GAIN_SIXTEEN);    // 16x gain  +/- 0.256V  1 bit = 0.125mV  0.0078125mV

  if (!ads.begin()) {
    mserial->printStrln("Failed to initialize ADS.");
  }
  pinMode(READY_PIN, INPUT);
  
 
  // Data Authenticity IC
  if (TEST_FINGERPRINT_ID_IC) {
    mserial->printStrln("Testing the Unique FingerPrind ID for Sensor Data Measurements");

    mserial->printStr("This Smart Device  Serial Number is : ");
    mserial->printStrln(CryptoICserialNumber(interface));

    mserial->printStrln("Testing Random Genenator: " + CryptoGetRandom(interface));
    mserial->printStrln("");

    mserial->printStrln("Testing Sensor Data Validation hashing");
    mserial->printStrln( macChallengeDataAuthenticity(interface, "TEST IC"));
    mserial->printStrln("");
  }

  mserial->printStrln("\nMicrocontroller specifications:");
  interface->CURRENT_CLOCK_FREQUENCY = getCpuFrequencyMhz();
  mserial->printStr("Internal Clock Freq = ");
  mserial->printStr(String(interface->CURRENT_CLOCK_FREQUENCY));
  mserial->printStrln(" MHz");

  interface->Freq = getXtalFrequencyMhz();
  mserial->printStr("XTAL Freq = ");
  mserial->printStr(String(interface->Freq));
  mserial->printStrln(" MHz");

  interface->Freq = getApbFrequency();
  mserial->printStr("APB Freq = ");
  mserial->printStr(String(interface->Freq / 1000000));
  mserial->printStrln(" MHz");

  interface->setMCUclockFrequency( interface->WIFI_FREQUENCY);
  mserial->printStrln("setting Boot MCU Freq to " + String(getCpuFrequencyMhz()) +"MHz");
  mserial->printStrln("");

  // init BLE
  BLE_init();

    // init BLE
  BLE_init();

  //init wifi
  mWifi->init(interface, drive, interface->onBoardLED);
  mWifi->setTxPower = WIFI_POWER_8_5dBm;
  mWifi->OTA_FIRMWARE_SERVER_URL = "https://github.com/aeonSolutions/openScience-Smart-DAQ-to-Upload-Live-Experimental-Data-to-a-Data-Repository/releases/download/openFirmware/firmware.bin";
  
  mWifi->add_wifi_network("XXXXXXXXXXXXXXX","XXXXXXXXXXXXXXXX");
  mWifi->ALWAYS_ON_WIFI = false;

  mWifi->WIFIscanNetworks(true);

  // check for firmwate update
  mWifi->startFirmwareUpdate();
  
  mserial->printStrln( "\nRequesting Geo Location FingerPrint  =====================================" );
  mWifi->get_ip_geo_location_data("", true);
  
  ESP32Time rtc(0);
  rtc.setTime( mWifi->requestGeoLocationDateTime );

  mserial->printStrln("Internet IP       : " + mWifi->InternetIPaddress );
  mserial->printStrln("Geo Location Time : " + String( rtc.getDateTime(true) ) );
  if ( mWifi->geoLocationInfoJson.isNull() == false ){
    float lat =0.0f;
    float lon = 0.0f;

    if( mWifi->geoLocationInfoJson.containsKey("lat")){
      lat = mWifi->geoLocationInfoJson["lat"];
      mserial->printStr( "Latitude : " + String(lat,4) );
    }else{
      mserial->printStr( "Latitude : - -" );
    }

    if( mWifi->geoLocationInfoJson.containsKey("lon")){
      lon = mWifi->geoLocationInfoJson["lon"];
      mserial->printStr( "  Longitude: " + String(lon,4) );
    }else{
      mserial->printStr( "  Longitude: - -" );
    }
    
    if( mWifi->geoLocationInfoJson.containsKey("regionName")){
      String regionName = mWifi->geoLocationInfoJson["regionName"];
      mserial->printStr( "\nLocation: " + regionName );
    }else{
      mserial->printStr( "\nLocation: - -" );
    }
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
void loop(){  
  if (millis() - beacon > 60000) {    
    beacon = millis();
    mserial->printStrln("(" + String(beacon) + ") Free memory: " + addThousandSeparators( std::string( String(esp_get_free_heap_size() ).c_str() ) ) + " bytes\n", mSerial::DEBUG_TYPE_VERBOSE, mSerial::DEBUG_ALL_USB_UART_BLE);
  }

  if ( (WiFi.status() != WL_CONNECTED) && ( millis() - statusTime > 30000 ) ) { //10 sec
    statusTime = millis();
    interface->onBoardLED->led[1] = interface->onBoardLED->LED_GREEN;
    interface->onBoardLED->statusLED(100, 0.04);
  }

  // .............................................................................
  // disconnected for at least 3min
  // change MCU freq to min
  if ( mWifi->ALWAYS_ON_WIFI == false && mWifi->getBLEconnectivityStatus() == false && ( millis() - mWifi->$espunixtimeDeviceDisconnected > 180000) && interface->CURRENT_CLOCK_FREQUENCY >= interface->WIFI_FREQUENCY) {
    mserial->printStrln("setting min MCU freq.");
    
    btStop();
    mWifi->setBLEconnectivityStatus(false);
    mWifi->stop();
    
    interface->onBoardLED->led[0] = interface->onBoardLED->LED_RED;
    interface->onBoardLED->led[1] = interface->onBoardLED->LED_GREEN;
    interface->onBoardLED->statusLED(100, 2);
    
    interface->setMCUclockFrequency(interface->MIN_MCU_FREQUENCY);
    interface->onBoardLED->init();
  }

  // ................................................................................
  // Ligth Sleeep
  eTime = millis() - prevMeasurementMillis;
  if ( mWifi->getBLEconnectivityStatus() == false && interface->LIGHT_SLEEP_EN) {
    interface->onBoardLED->turnOffAllStatusLED();
    delay(100);    
    mWifi->stop();
    mserial->printStr("Entering light sleep for "+String( (MEASUREMENT_INTERVAL - eTime) / 1000)+" sec ....");
    esp_sleep_enable_timer_wakeup( ( ( MEASUREMENT_INTERVAL - eTime) / 1000)  * uS_TO_S_FACTOR);
    delay(100);
    esp_light_sleep_start();
    mserial->printStrln("wake up done.");
    mWifi->start();
  }
  prevMeasurementMillis = millis();

  
  //onBoardSensors->request_onBoard_Sensor_Measurements();
  
  // .....................................................................
  // Telegram
  telegram->runTelegramBot(EMP_voltage[EMP_voltage_idx], onBoardSensors->ONBOARD_TEMP, onBoardSensors->ONBOARD_HUMIDITY);

  // .............................................................
  // do measurements

  if (millis() - MQTT_beacon > MEASUREMENT_INTERVAL) {
    int16_t res1= ads.readADC_SingleEnded(1);
    int16_t res2= ads.readADC_SingleEnded(2);
    double tension_A1  = ads.computeVolts(res1);
    double tension_A2  = ads.computeVolts(res2);
    tension_dif = tension_A1 - tension_A2;
 
    EMP_voltage[EMP_voltage_idx] = tension_dif;
    onBoardSensors->request_onBoard_Sensor_Measurements();
    EMP_temp[EMP_voltage_idx] = onBoardSensors->ONBOARD_TEMP;
    EMP_humi[EMP_voltage_idx] = onBoardSensors->ONBOARD_HUMIDITY;
    
    EMP_voltage_idx ++;
    if ( EMP_voltage_idx > 99 )
      EMP_voltage_idx = 0;
 
    mserial->printStrln("Voltage A1: " +String(tension_A1)+ "mV" ); 
    mserial->printStrln("Voltage A2: " +String(tension_A2)+ "mV" ); 
    mserial->printStrln("Differential 1-2: " + String(tension_dif) + "mV");
        
    bool pub_ok = true;     
    MQTT_beacon = millis();
    
    if (WiFi.status() != WL_CONNECTED)
      mWifi->connect(10000,5);
    if (WiFi.status() == WL_CONNECTED && EMP_voltage_idx != 0){
      MQTT_connect();

        for (int i=EMP_voltage_idx; i>=0; i--){
          mserial->printStrln("EMP("+String(i)+"): " + String(EMP_voltage[i],4) +" mV");    
          if ( true != publishData( &emp, EMP_voltage[i] ) ){
            publishData( &temp,  EMP_temp[i] );
            publishData( &humidity, EMP_humi[i] );
            pub_ok = false;
            break;
          }
          if ( EMP_voltage_idx > 1){
            mserial->printStrln("61 sec delay to avoid Adafruit temporary ban");
            delay(61000);
          }
        }      
      if (pub_ok)
        EMP_voltage_idx = 0;
    }
  }

  // ................................................................................    

  if (mserial->readSerialData()){
    GBRLcommands(mserial->serialDataReceived, mserial->DEBUG_TO_USB);
  }
  // ................................................................................    

  if (mserial->readUARTserialData()){
    GBRLcommands(mserial->serialUartDataReceived, mserial->DEBUG_TO_UART);
  }
  // ................................................................................


  if (newBLESerialCommandArrived){
    xSemaphoreTake(MemLockSemaphoreBLE_RX, portMAX_DELAY); 
      newBLESerialCommandArrived=false; // this needs to be the last line       
    xSemaphoreGive(MemLockSemaphoreBLE_RX);

    GBRLcommands($BLE_CMD, mserial->DEBUG_TO_BLE);
  }


  // ....................................................................................
  // OTA Firmware
  if ( mWifi->forceFirmwareUpdate == true )
    mWifi->startFirmwareUpdate();



// ---------------------------------------------------------------------------
  if (millis() - lastMillisWIFI > 60000) {
    xSemaphoreTake(interface->MemLockSemaphoreCore2, portMAX_DELAY);
    waitTimeWIFI++;
    lastMillisWIFI = millis();
    xSemaphoreGive(interface->MemLockSemaphoreCore2);
  }

}
// -----------------------------------------------------------------
